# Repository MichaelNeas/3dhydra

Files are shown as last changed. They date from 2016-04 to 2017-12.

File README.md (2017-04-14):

## Hydra Website
#### Senior Project - 3D Printed Elbow-Down Prosthetic

## We won 1st place at UCONN Senior Design!!!!!!!!!

## Features
- Customizable Solidworks files aimed for scalability and reprintability.
- Intelligent Ardunio Servo Control
- Dynamic Android Phone Application
- Moto 360 Wearable Technology

## Motivation
The reason for Hydra's existence is purely based on our love for technology and desire to give back.  We are 4 Computer Science and Engineering students from The University of Connecticut and we wanted our Senior Design Project to be different.  A project that we could feel significant accomplishment from and learn as much as we possibly could in the process.  

## Contributors
- Michael Neas 
- Daniel Demarco
- Ted Jensen 
- Joey Hanlon

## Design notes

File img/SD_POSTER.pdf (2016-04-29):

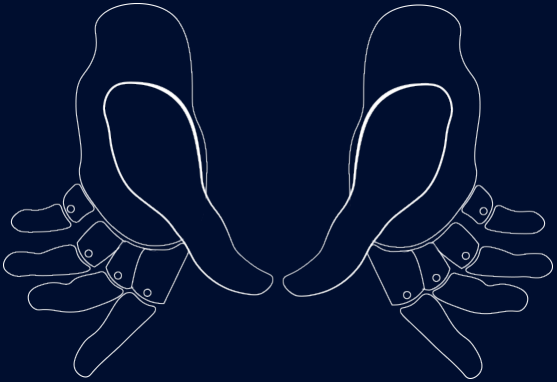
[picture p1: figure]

# Objective

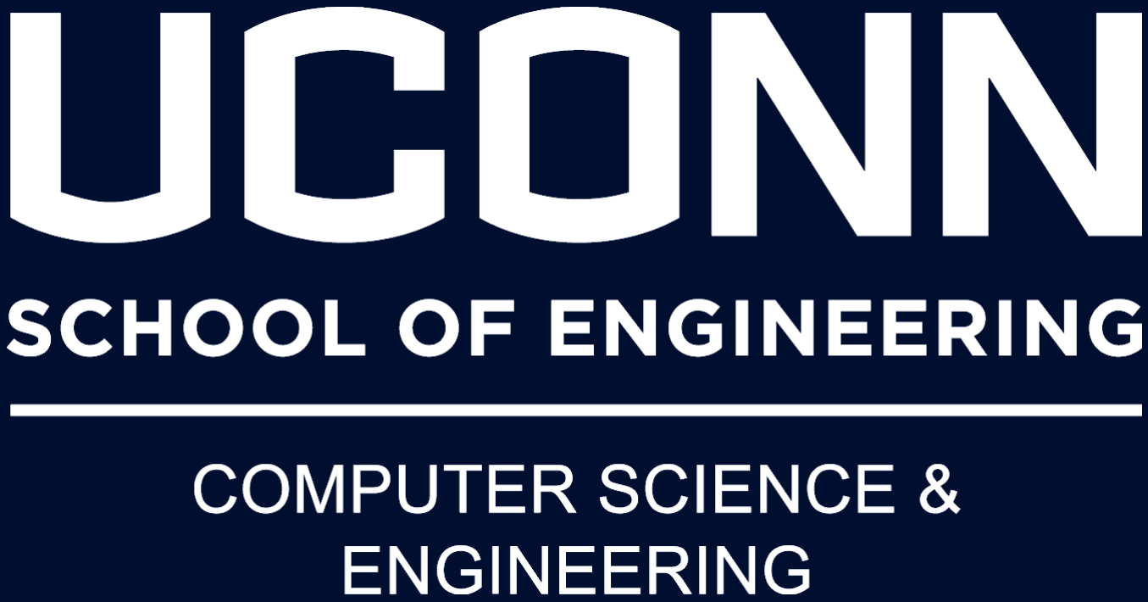
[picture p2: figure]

# Hydra

# A low-cost elbow down prosthetic

# Arduino

Advisor | Yufeng Wu
Group | 13
Members | Theodore Jensen

## Michael Neas Daniel Demarco Edward Hanlon

Mechanics | Software

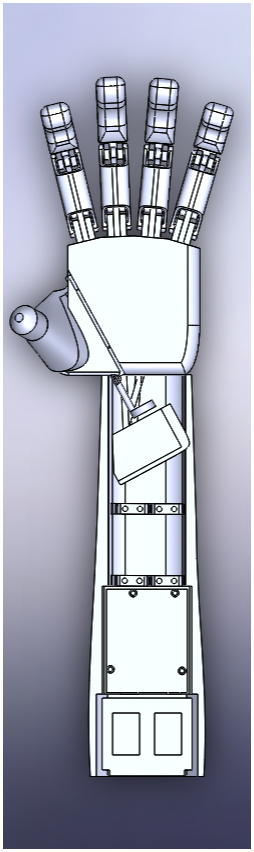
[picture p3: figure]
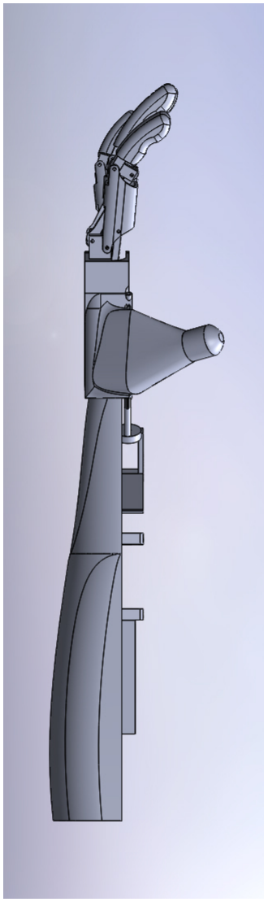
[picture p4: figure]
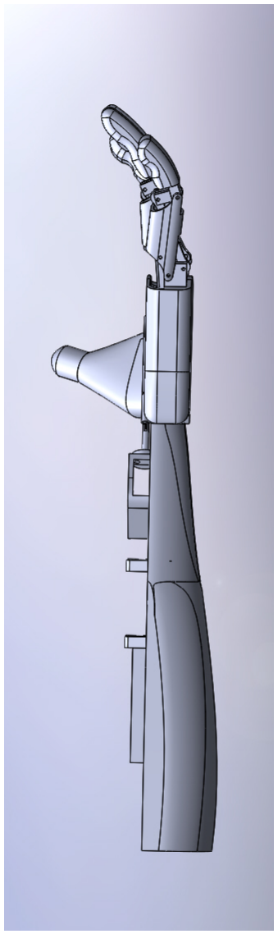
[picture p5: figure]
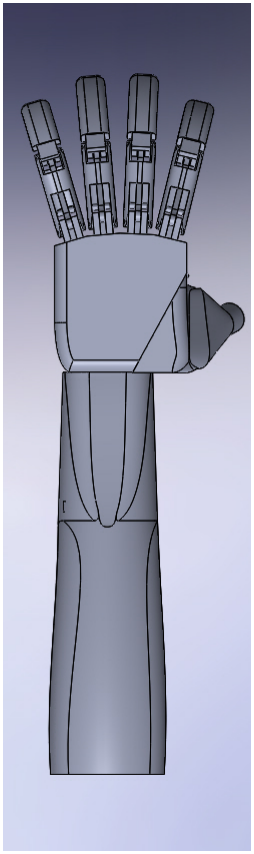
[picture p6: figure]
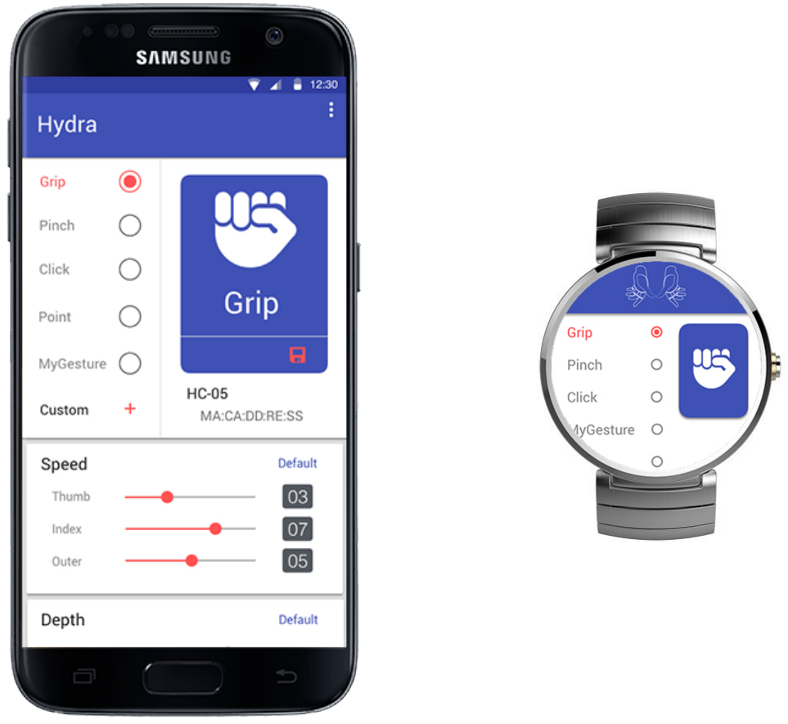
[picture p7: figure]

Arduino

Vin

EMG_PIN

5V

GND

servoPin[2]
servoPin[1]
servoPin[0]

TX_PIN
RX_PIN

Muscle Sensor v3.0
+Vs
GND
-Vs

Sig
GND

HC-05

EN
RXD

TXD
GND
VCC

STATE
Batt1
9V | Batt2

9V

Servo

GND
VCC
Sig

Servo

GND
VCC
Sig

Servo

GND
VCC
Sig

R1

10k

R2

20k

Control: The microcontroller manages 5 control parameters:

Parameter 1 - Dynamic or Static
Static movements hold after a grip

Parameter 2 - Action Threshold
Percentage of full voltage range at which a flex is registered

Parameter 3 - Write Delay
Delay between Arduino loops

Parameter 4 - Grip Depth per-Servo - how far each Servo extends Percentage of full servo extension range (0 implies servo is inactive)

Parameter 5 - Responsivity per-Servo
Servo value increment (grip speed)

Communication: Bluetooth messages follow the format of “Parameter#=val;” or “Parameter#=val,val,val;” for per-servo settings

Multiple parameter strings can be sent in a single message
(i.e. “1=D;2=0.5;3=5.0;4=100,100,100;5=5.0,5.0,5.0;“)

## Design an elbow down prosthetic without sacrificing the features and functionality of high-end alternatives for less than $300. This is made possible by leveraging new and inexpensive technologies such as 3D-printing, smart phones, microcontrollers, and

various open source software packages.

- All parts (excluding electronics) are 3D-printed in PLA plastic
- All 22 uniquely designed parts are scalable, allowing the prosthetic to be sized accordingly prior to printing
- Fully mechanical construction provides accurate motion and maintains rigidity throughout finger travel

Gestures: Select, customize, and save different modes for prosthetic to operate in

Live updating: Control parameters stored in the arduino update in live time; as they are modified on the phone, they are instantly updated in the prosthetic

Smart watch: Android wear companion app for quick gesture selection

Personalize: Users are able to make Hydra work the way they desire with flex threshold calibration and full parameter control

# System Summary

User

Watch Phone

EMG
Sensors

Bluetooth

Arduino

Servos

Gesture

Electronic schematic

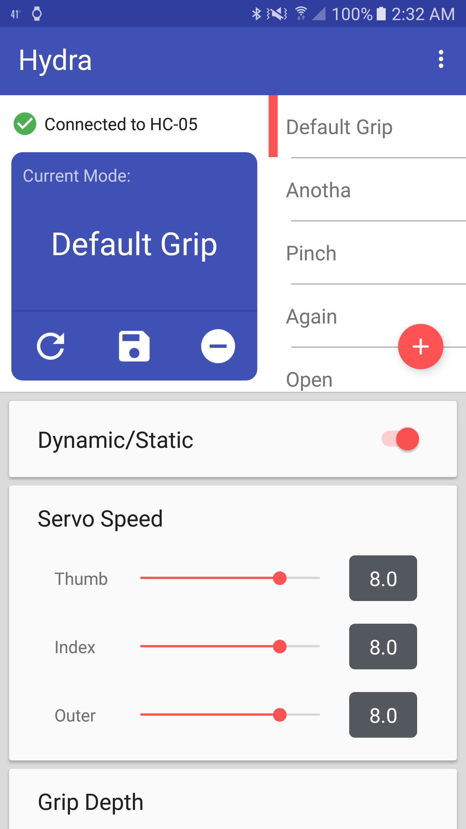
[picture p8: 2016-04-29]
img/phoneShot.png

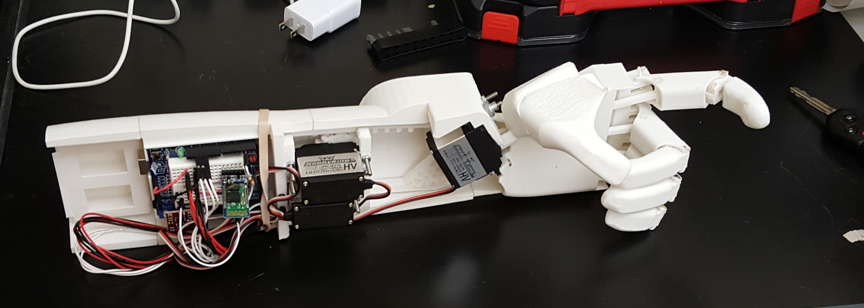
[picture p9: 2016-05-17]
img/durableHydra.jpg

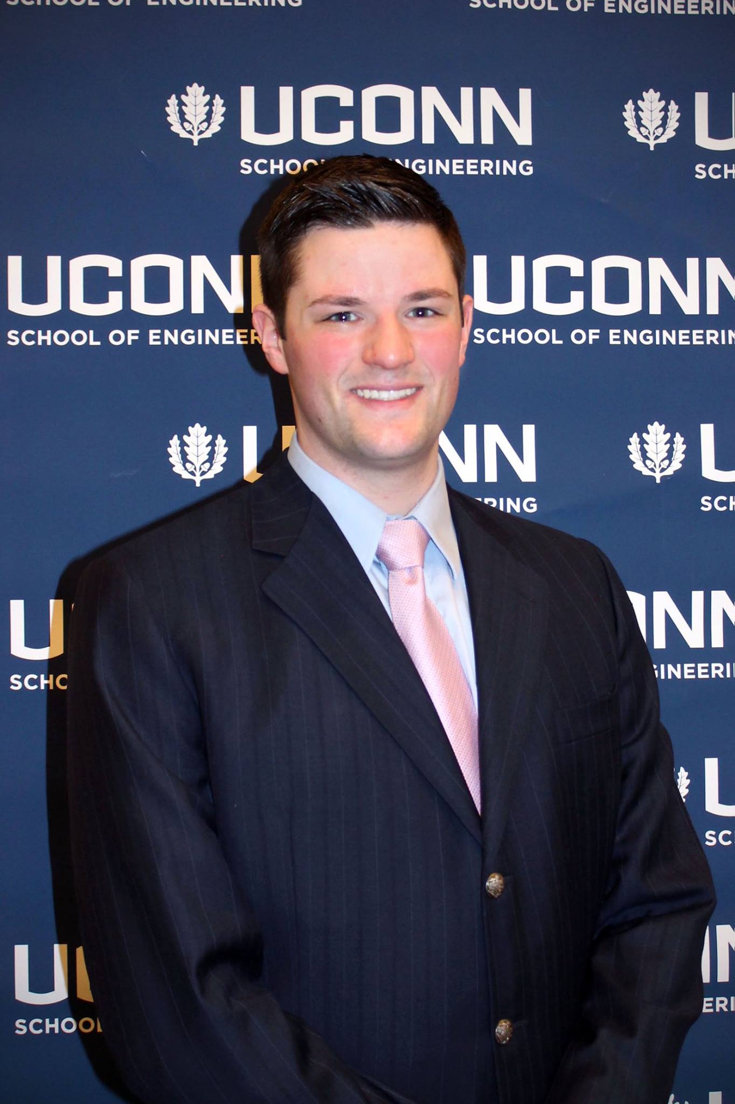
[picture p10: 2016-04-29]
assets/img/Joey_Hanlon_Profile_Img.jpg

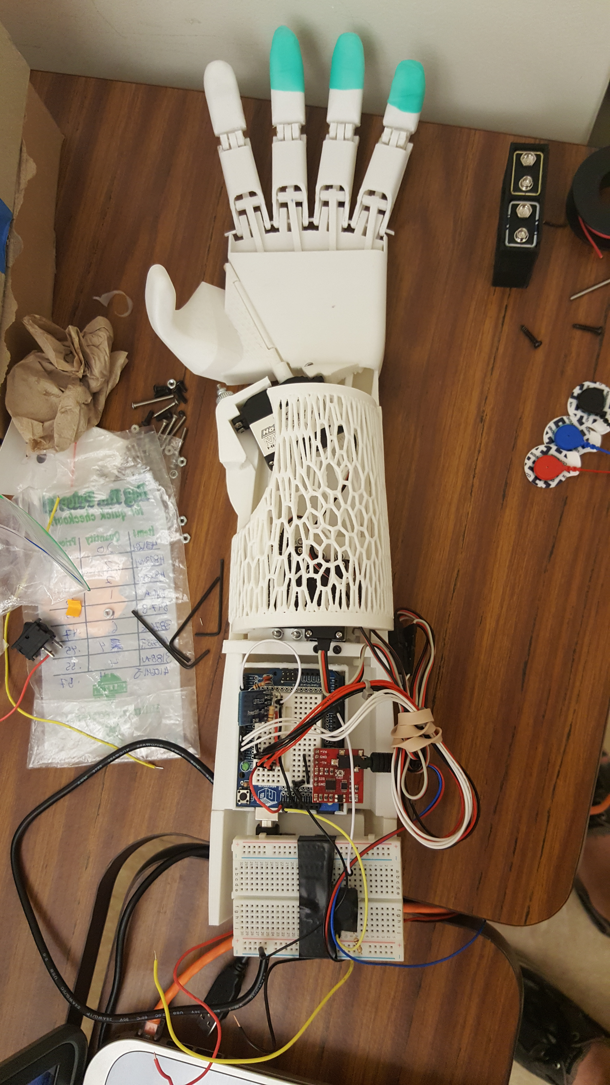
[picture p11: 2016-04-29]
img/hydratop.jpg

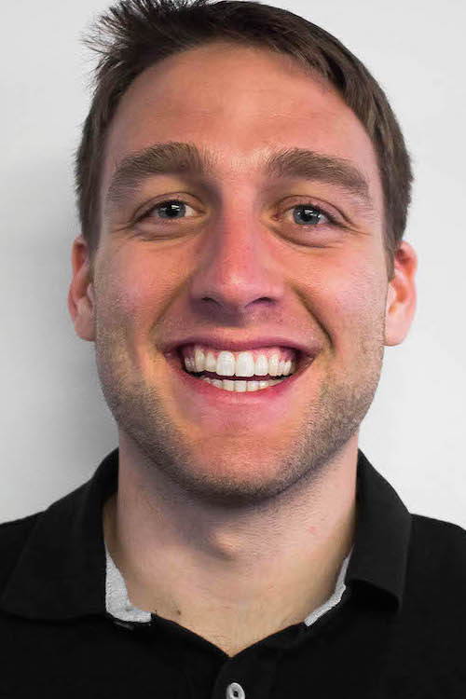
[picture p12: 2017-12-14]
assets/img/Mike_Neas_Profile_Picture.jpg

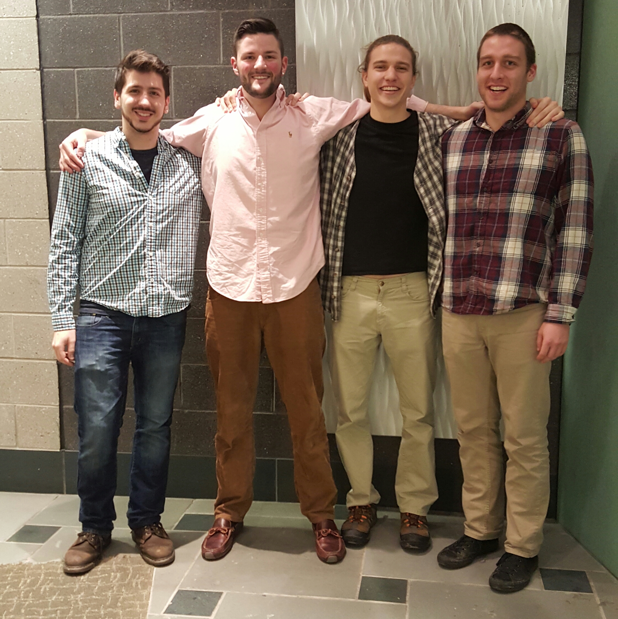
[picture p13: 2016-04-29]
assets/img/Team_Picture.jpg

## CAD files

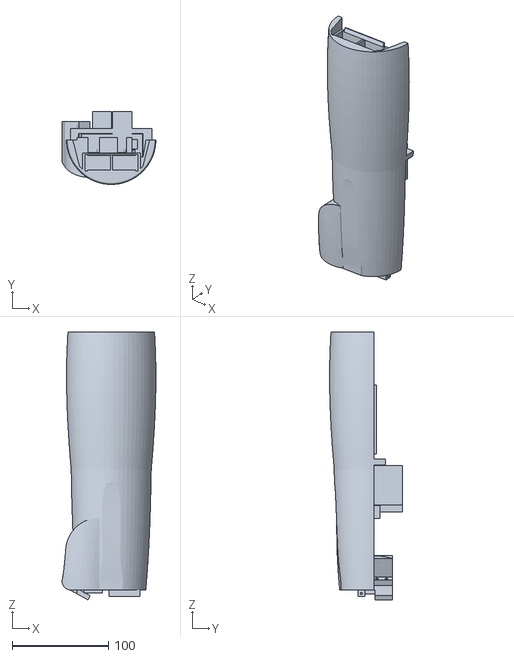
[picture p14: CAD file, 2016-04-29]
assets/stl/Hydrafullforearm.STL
97.5 x 75.8 x 278.5

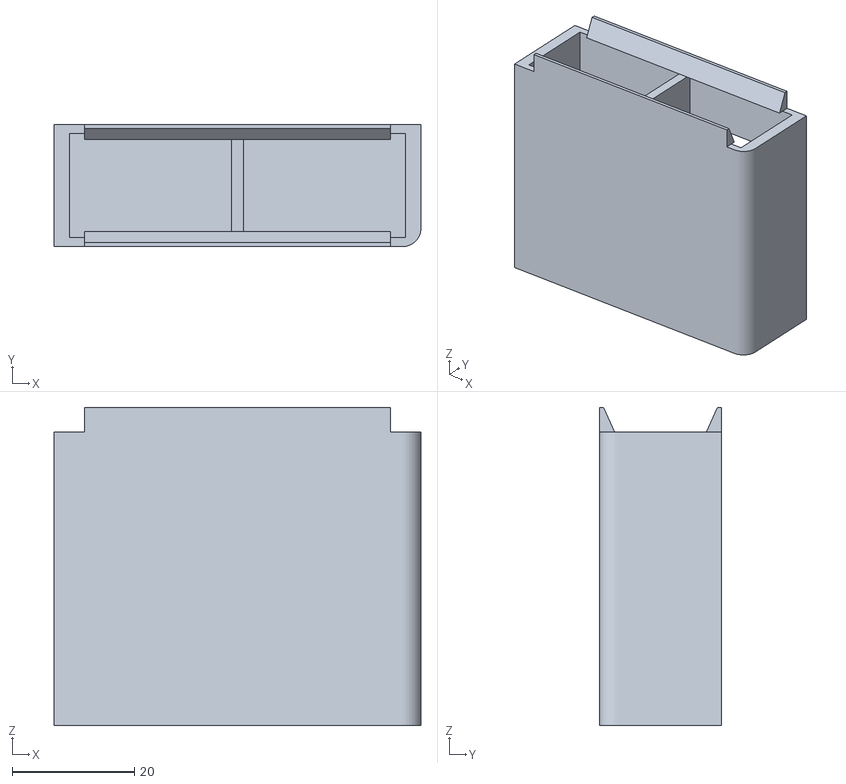
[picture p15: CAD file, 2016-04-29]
assets/stl/Hydra_-_HydraForeArm-2_powerSupply-1.STL
60.0 x 20.0 x 52.0

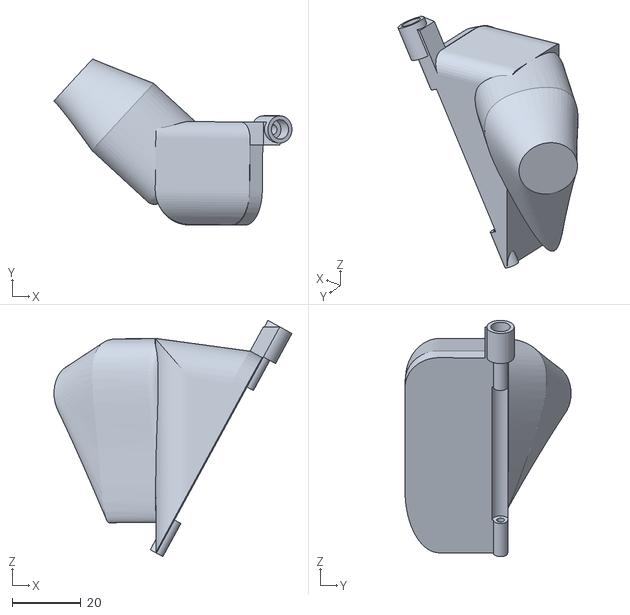
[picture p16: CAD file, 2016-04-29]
assets/stl/Hydra_-_HandKnuckleCombine-1_thumbSem-1_thumb-1.STL
69.4 x 48.5 x 68.9

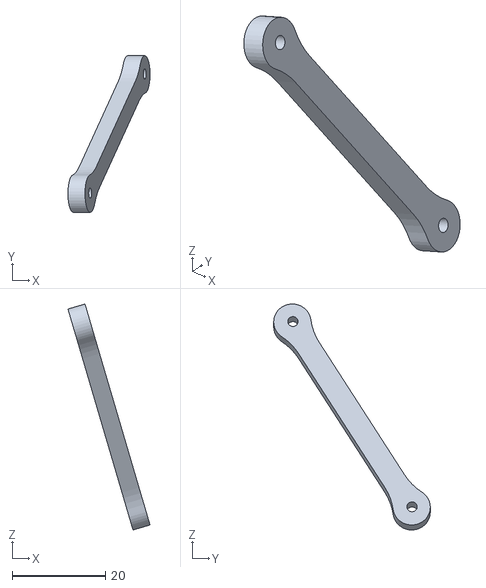
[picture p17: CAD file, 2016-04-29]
assets/stl/Hydra_-_pinkFinger-1_stablizer-1.STL
17.6 x 33.6 x 48.4

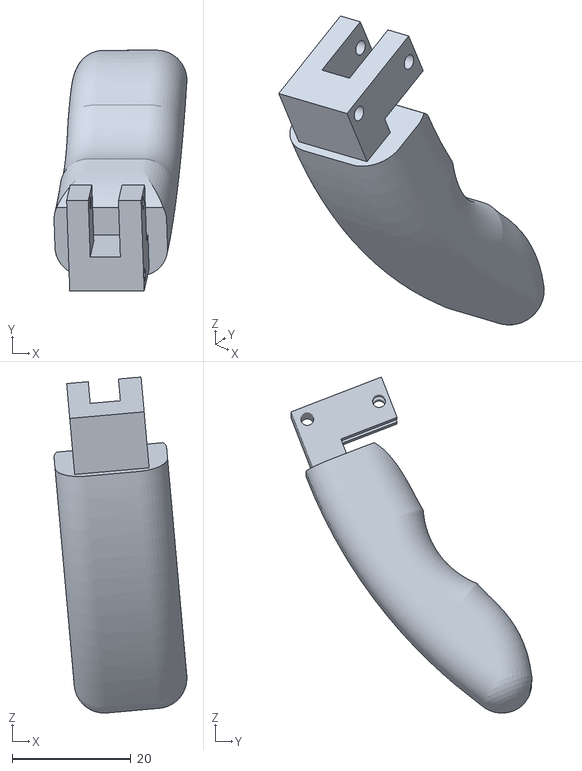
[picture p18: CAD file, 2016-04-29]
assets/stl/Hydra_-_ringFinger-1_distal_middle-1.STL
22.4 x 40.6 x 56.6

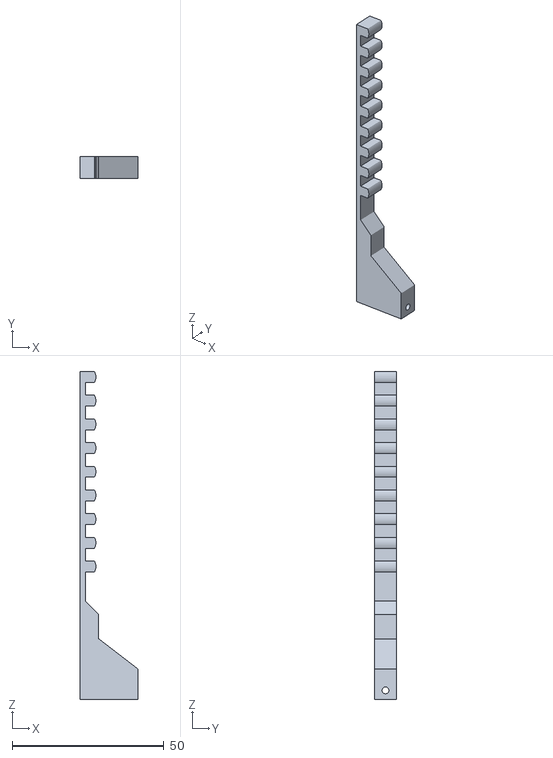
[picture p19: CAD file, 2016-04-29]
assets/stl/Hydra_-_HydraForeArm-2_RackandPinion-1_pointerPinion-3.STL
19.2 x 7.30 x 108.0

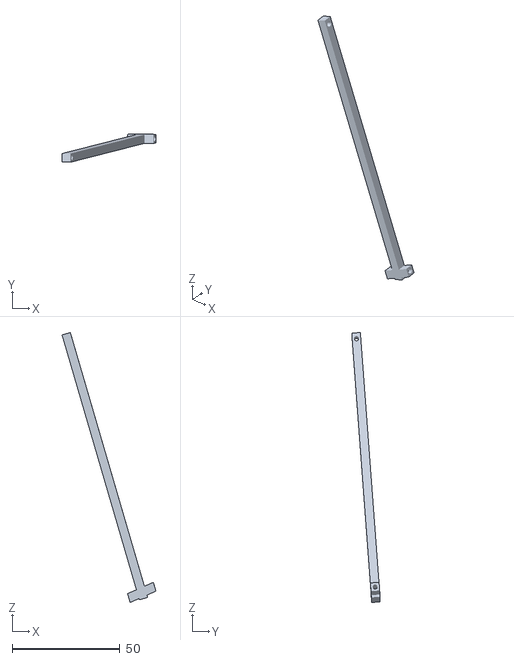
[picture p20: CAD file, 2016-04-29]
assets/stl/Hydra_-_pinkFinger-1_pinkyActuator-1.STL
43.5 x 13.2 x 125.2

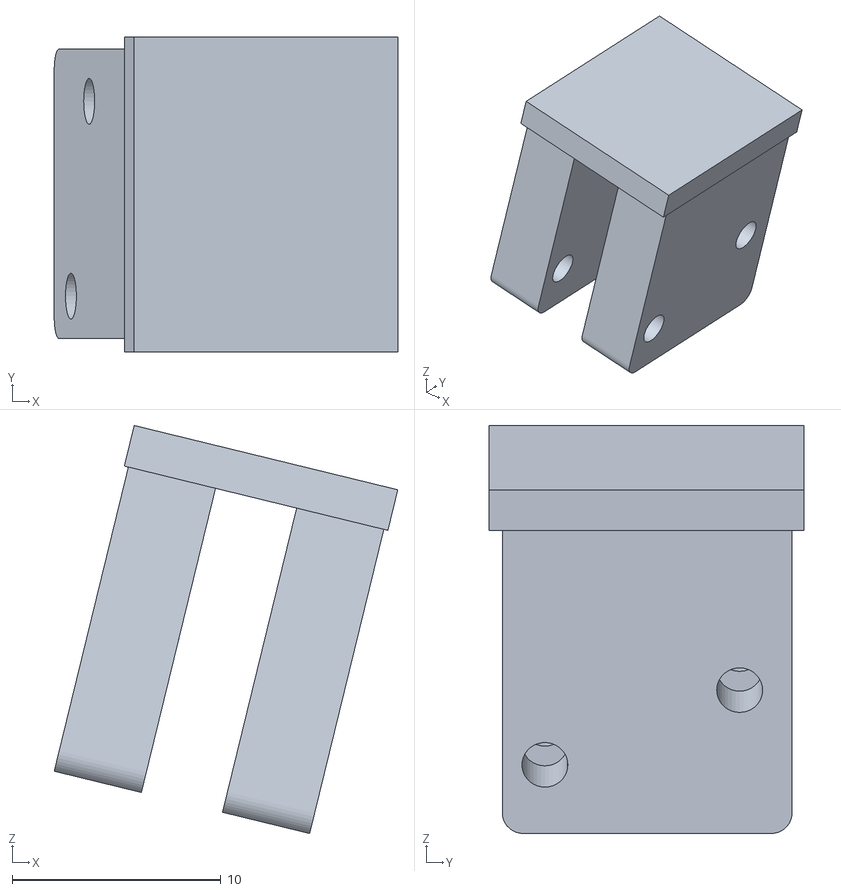
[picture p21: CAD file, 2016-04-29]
assets/stl/Hydra_-_HandKnuckleCombine-1_knuckle-2.STL
16.5 x 15.1 x 19.5

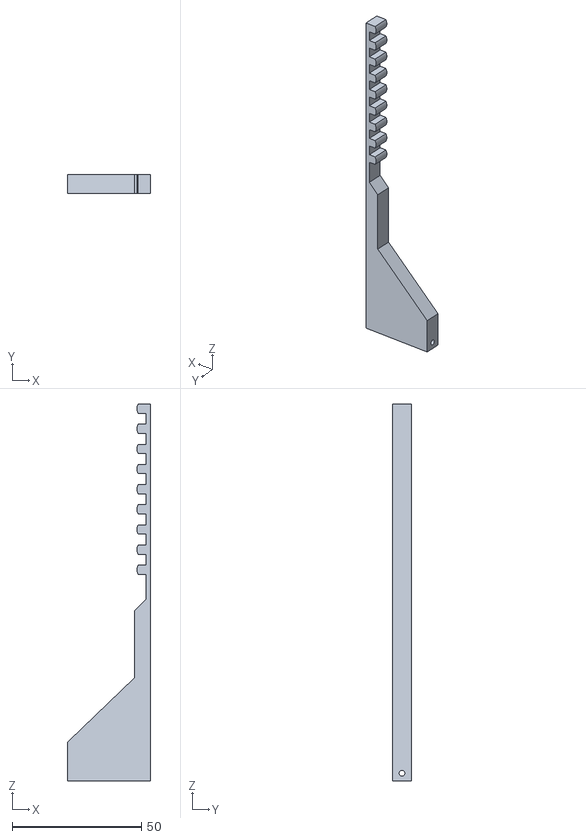
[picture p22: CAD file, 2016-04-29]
assets/stl/Hydra_-_HydraForeArm-2_RackandPinion-1_threeFingerPinion-1.STL
32.2 x 7.30 x 146.0

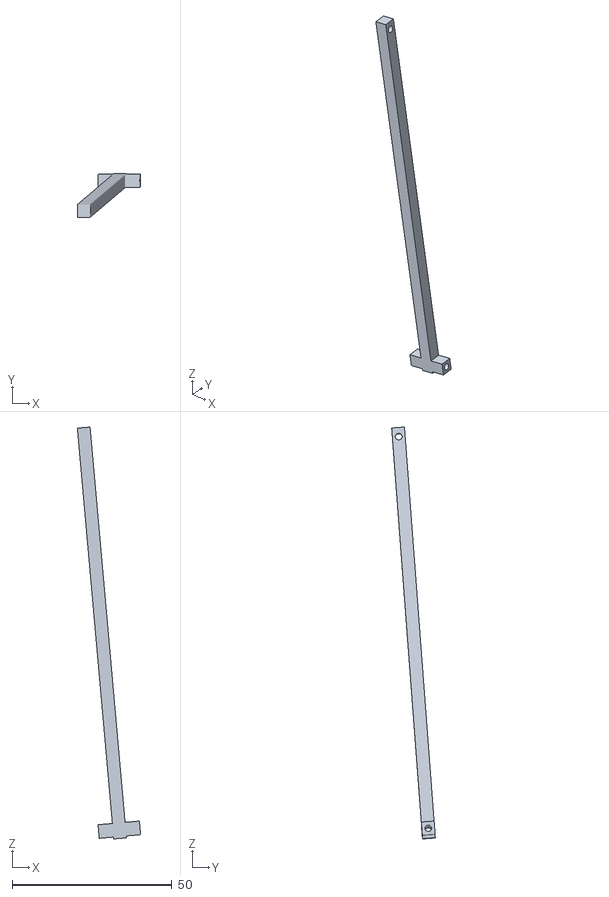
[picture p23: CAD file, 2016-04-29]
assets/stl/Hydra_-_ringFinger-1_ringActuator-1.STL
19.8 x 13.6 x 128.8

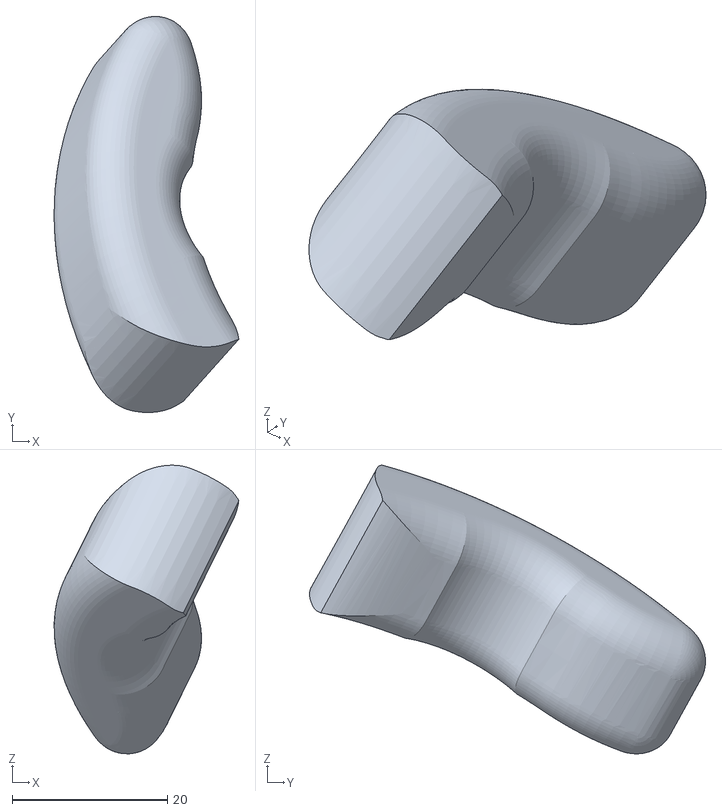
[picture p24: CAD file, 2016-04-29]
assets/stl/Hydra_-_HandKnuckleCombine-1_thumbSem-1_ThumbDistal-1.STL
23.8 x 51.1 x 37.2

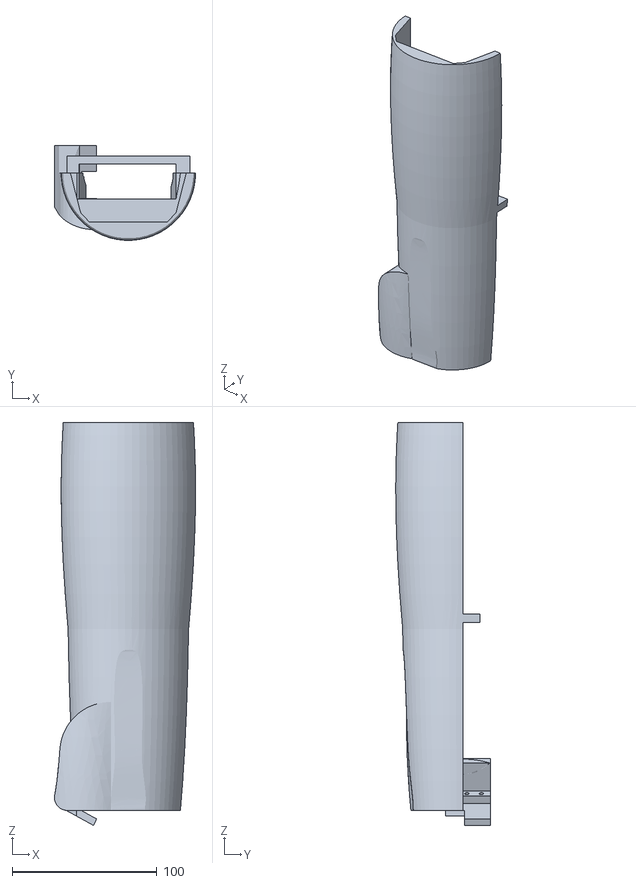
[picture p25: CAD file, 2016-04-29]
assets/stl/Hydra_-_HydraForeArm-2_halfForearm-1.STL
97.5 x 65.4 x 278.5

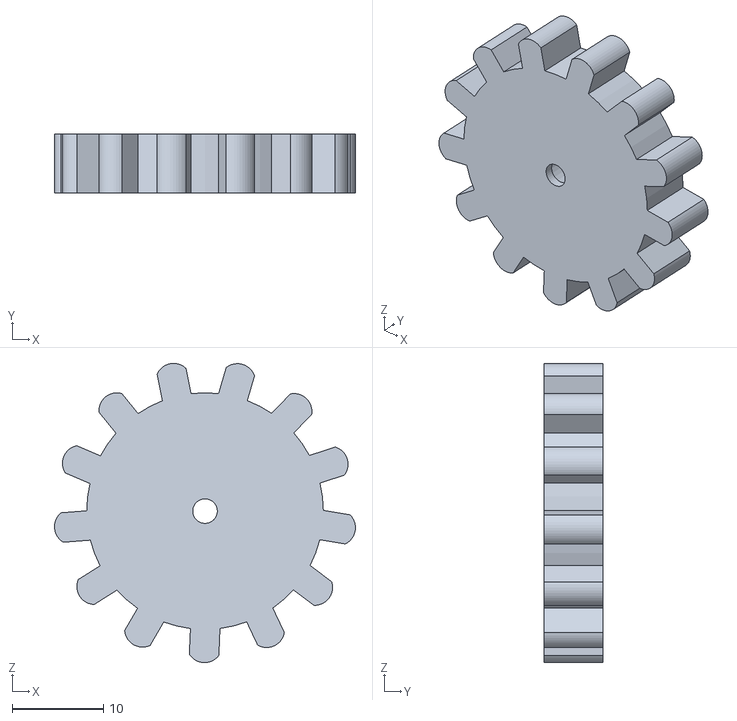
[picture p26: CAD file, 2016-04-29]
assets/stl/Hydra_-_HydraForeArm-2_RackandPinion-1_gear-1.STL
33.1 x 6.50 x 32.9

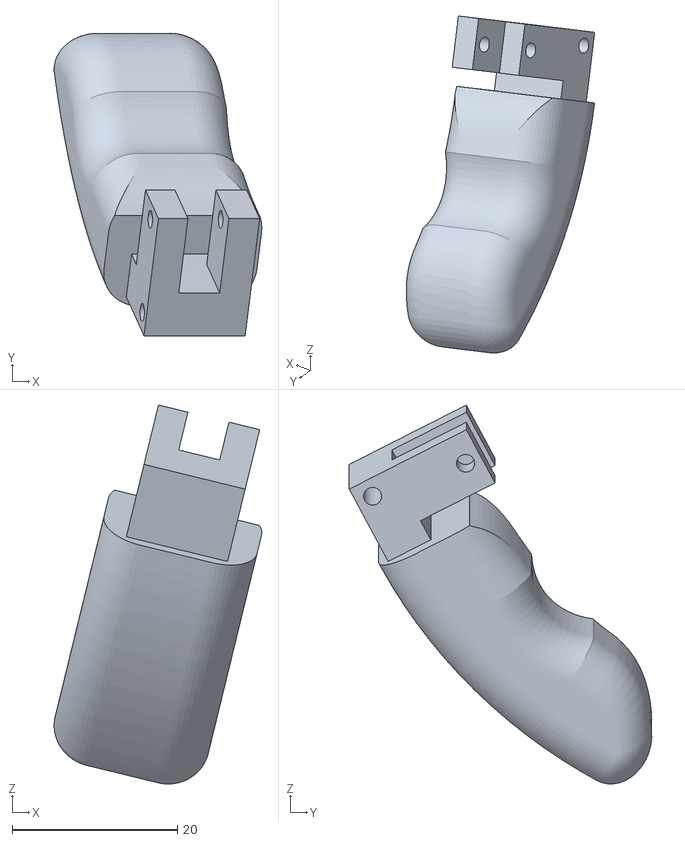
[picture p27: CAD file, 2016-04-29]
assets/stl/Hydra_-_pointerFinger-1_pointerDM-1.STL
25.1 x 36.6 x 45.8

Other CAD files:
assets/stl/Hydra_-_middle_ringFingers-1_distal_middle-1.STL
assets/stl/Hydra_-_pointerFinger-1_actuator-1.STL
assets/stl/Hydra_-_middle_ringFingers-1_fingerREDUX-1.STL
assets/stl/Hydra_-_pinkFinger-1_pinkyDM-1.STL
assets/stl/HydraForeArmtogether.STL
assets/stl/Hydra_-_HandKnuckleCombine-1_palm-1.STL
assets/stl/Hydra_-_HydraForeArm-2_RackandPinion-1_ServoModel-1.STL
assets/stl/Hydra_-_HydraForeArm-2_RackandPinion-1_servoRail-1.STL
assets/stl/Hydra_-_HydraForeArm-2_arduinosHome-1.STL
assets/stl/Hydra_-_middle_ringFingers-1_middleActuator-1.STL
assets/stl/RackandPinion.STL
assets/stl/arduinosHome.STL
assets/stl/ringFinger.STL

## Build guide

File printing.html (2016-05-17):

### Time Per Print

Part | Print Time
Palm | 6h 20m
Front Forearm | 8h 50m
Middle Forearm | 9h 21m
Base Forearm | 4h 10m
Thumb | 4h 9m
Distal | 3h 10m
GearBox | 3h 3m
Proxal | 2h 13m
Pinions | 1h 7m
Gears | 50m
Actuators | 45m
Stabilizers | 23m

### Printer Settings

Settings | Values
Extruder Temp | 195-210 degrees C (based on filament color)
Bed Temp | 70 degrees C
Printable Area | 200x200x150 mm
Infill | Honeycomb, 25-35%
Raft | 2 layer (if curved surface)
Perimeter Walls | 2 layer
Filament | PLA

### Cost of Project

This project was funded entirely by us.

Parts | Cost(usd)
Arduino Micro | $19.88
MS: V3(x2) | $52.00
BioMedical Sensors(10 pack) | $8.00
Servo: High Torque/Full Rotation(x3) | $42.00
3d Printer | $300.00
Hardware Misc | $30.00
Bluetooth Module | $5.00
Grand Total | <<$500

### X-Wing Alliciousness

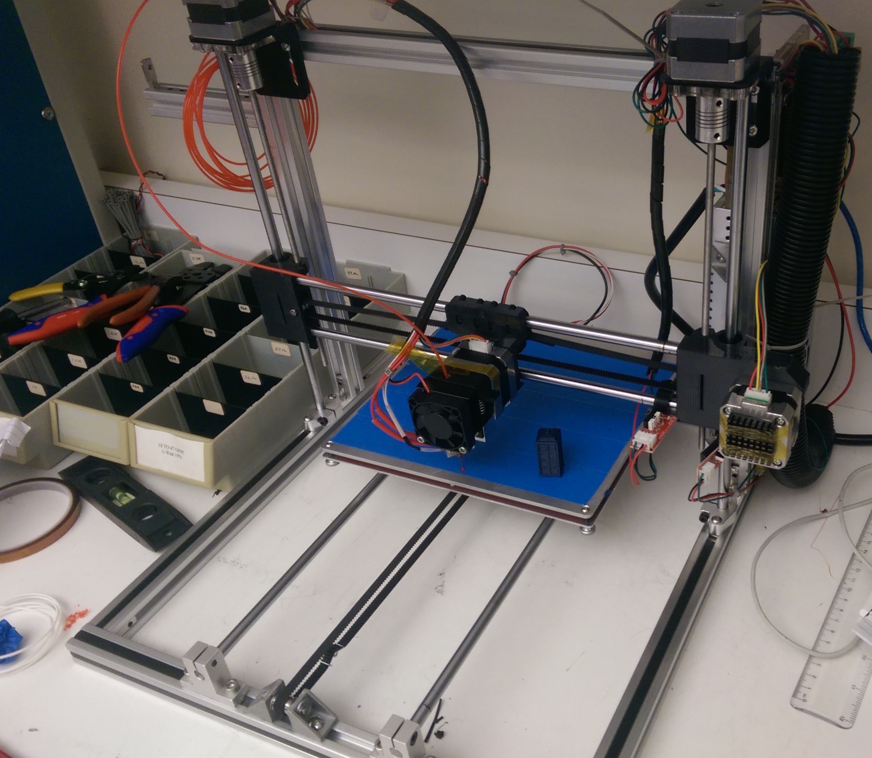
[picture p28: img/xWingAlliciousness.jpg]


### Printed Pieces

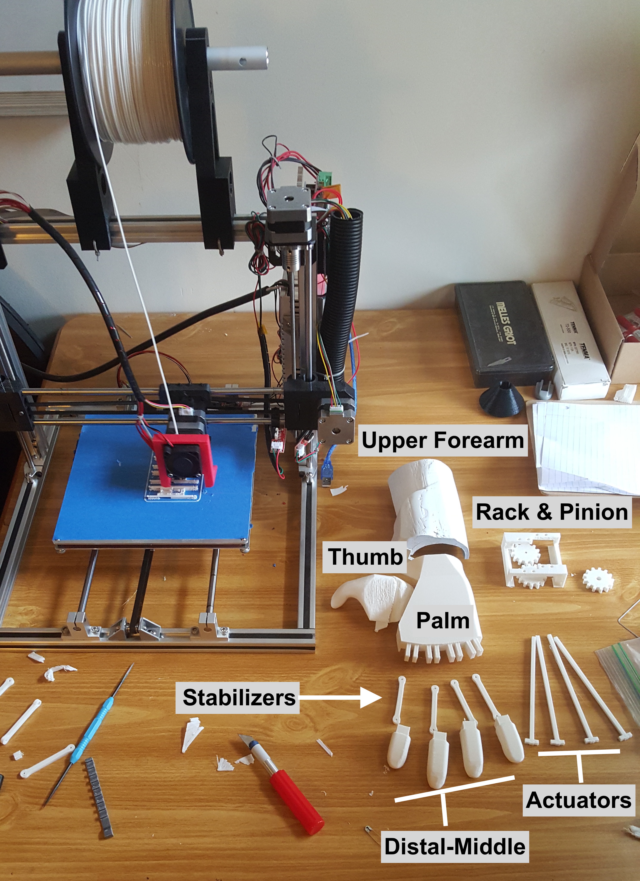
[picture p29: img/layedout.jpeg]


### Solder Points

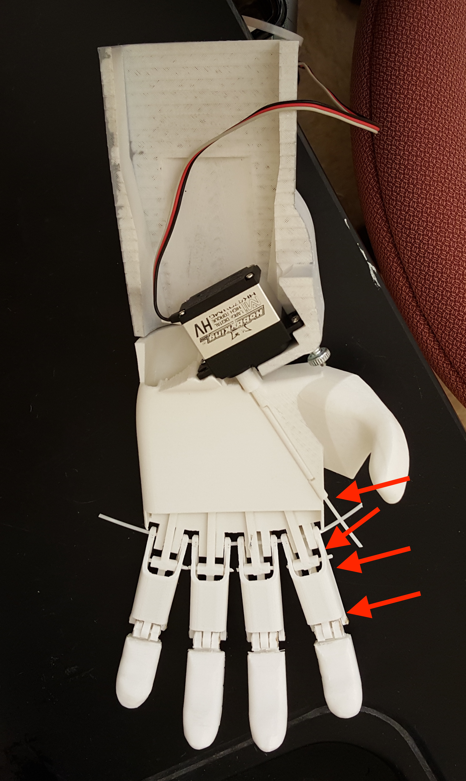
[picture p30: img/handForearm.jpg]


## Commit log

2016-04-24 Add STL Render and Navbar
    [arduinosHome.STL]
2016-04-26 Hydra stl
2016-04-29 Stl push
    [HydraForeArmtogether.STL, Hydra_-_HandKnuckleCombine-1_knuckle-2.STL, Hydra_-_HandKnuckleCombine-1_palm-1.STL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]
2016-04-29 STL rendering
2016-04-29 Add images to landing screen
2016-04-29 Printer stats
